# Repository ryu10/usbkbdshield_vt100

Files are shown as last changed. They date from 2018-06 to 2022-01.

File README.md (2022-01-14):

# USB Keyboard Shield for VT100

__Rev. 2.1__

## About

This shield connects a standard USB keyboard to the DEC VT100 terminal.

### Features

* All keys on the VT100 keyboard are mapped to the USB keyboard keys.
* VT100 keyboard LEDs and bell are emulated on the shield PCB.

The Gerber file, BOM, schematics and Arduino sketch for the shield are included in this repo. For the steps to assemble, program and connect the shields, please see the sections below.

__Note:__ this shield uses the USB Host Shield from Circuits@Home.

Please use the information in this repo at your own risk. No warranty or guarantee is provided.

## Required Components

- USB Keyboard Shield for VT100 (the shield from this repo)
- [USB Host Shield by Circuits@Home](https://www.circuitsathome.com/arduino_usb_host_shield_projects/), the "full-sized board"
- Arduino Uno
- Keyboard cable for VT100 (see "Keyboard Cable" below)
- USB Keyboard

## Steps

1. Assemble the shield
2. Build a keyboard cable
3. Program the Arduino
4. Connect the shields and cables

The details of each step are described in the next few sections.

## Assemble the Shield

The USB Keyboard Shield for VT100 can be assembled using the following info:

- PCB Gerber File: [usbkbd_vt100_2_1_gerber.zip](./usbkbd_vt100_2_1_gerber.zip)
- Schematic: [usbkbd_vt100_sch.pdf](./usbkbd_vt100_sch.pdf)
- BOM: [usbkbd_vt100_BOM_2_1.pdf](./usbkbd_vt100_BOM_2_1.pdf)

## Build the Keyboard Cable

To make the keyboard cable, connect these components:

 - 1/4 inch stereo plug/cable
 - 5-pin header connector

__PIN CONNECTIONS__

| Pin | Plug |  Value |
|-|-|-|
| 1* | - | (spk+)* |
| 2* | - | (spk-)* |
| 3 | Tip | +12V |
| 4 | Sleeve | GND |
| 5 | Ring | Signal |

  \* optional

The pin connector is attached to J1 header on the USB Keyboard shield for VT100. The stereo plug is connected to the keyboard port on VT100 terminal.

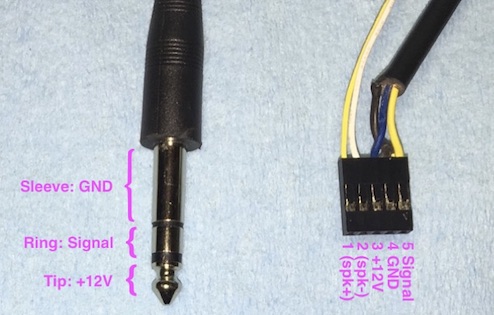
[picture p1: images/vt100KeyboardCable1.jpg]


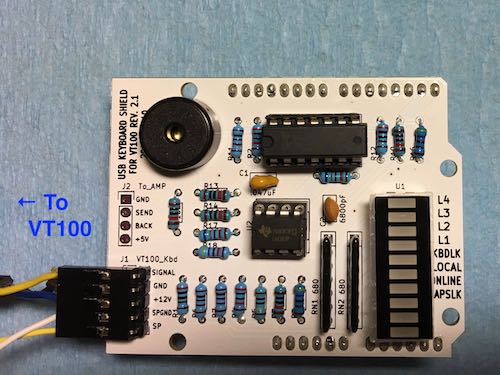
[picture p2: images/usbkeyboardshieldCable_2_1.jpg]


## Program the Arduino Uno

It is recommended to program the Arduino Uno before attaching the shields.

1. Install [USB Host Shield Library 2.0](https://github.com/felis/USB_Host_Shield_2.0) and [Timer1 Library](http://playground.arduino.cc/Code/Timer1) into Arduino IDE.

2. Clone or download this project.

3. Open the sketch `usbkeyboardvt100/usbkeyboardvt100.ino` in Arduino IDE, and program the Arduino Uno.

### Configuration Options

There are two options in `usbkeyboardvt100.ino`:
```
// SWAPCAPS: If defined, LeftCtrl and CapsLock are swapped on USB Keyboard.
#define SWAPCAPS

// SWAPLFBAR: If defined, swap LineFeed and '|\' key codes for VT100.
//#define SWAPLFBAR
```

Comment out/uncomment the `#define` lines as needed.

## Connect the Shields and Cables

1. Connect the USB keyboard to the USB connector on the USB Host Shield.
2. Connect the keyboard cable for VT100 to the J1 header on the USB Keyboard Shield.
3. Connect the keyboard cable to the keyboard port on VT100 terminal.
4. Stack and connect the Arduino Uno, the USB Host Shield, and the USB Keyboard Shield, in this order, from the bottom to the top (see the iamge below).
5. No external power supply is needed. The power is supplied via the VT100 keyboard cable.

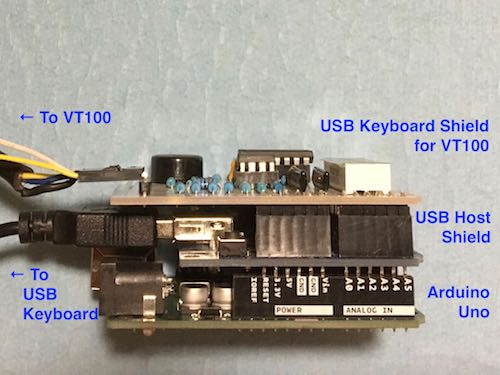
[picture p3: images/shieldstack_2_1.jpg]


## Key Mappings

Some hard-to-guess keys:

| VT100 Key | USB Keyboard Key |
|-|-|
| SET UP | F1, SysRq |
| CTRL | Caps Lock |
| CAPS LOCK | Left Ctrl |
| BREAK | Break |
| LINE FEED | End |
| NO SCROLL | Scroll Lock |
| PF1 | Num Lock, F9 |
| PF2 | (numpad) /, F10 |
| PF3 | (numpad) *, F11 |
| PF4 | Page Up, F12 |
|(numpad) , | (numpad) + |

The key mappings are defined in `usb_key_tbl[]` in `usbkeyboardvt100.h`. Also see "Configuration Options" above.

## Reference Configuration

The following configuration was used during development of this shield:

- USB Host Shield 2.0
- Arduino Uno R3
- VT100-WA / VT-180
- USB Keyboards: HP K1500 / Logitech K310

## Known Issues

1. Keyboard connected via a USB hub is not supported.

## GPL

The code is released under the GNU General Public License.

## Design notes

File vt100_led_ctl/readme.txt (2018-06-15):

vt100_led_ctl:

This directory contains two files that control VT100 keyboard LED's:

1.led_all_on.txt ... contains the ESC sequence that turns on L1 - L4.
0.led_all_off.txt ... contains the ESC sequence that turns off L1 - L4.

To turn on/off the keyboard LED's, display the file contents on the VT100 session with the host machine.

Example:

% cat 1.led_all_on.txt
% cat 0.led_all_off.txt

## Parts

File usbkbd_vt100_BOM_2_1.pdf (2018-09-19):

### USB Keyboard Shield for VT100 Rev. 2.1: Shield Components

Ref | Qty | Value | Desc | Mouser P/N | Mouser URL
C1 | 1 | .047uF | Capacitor | 810-FA16C0G2A473JRU6 | https://www.mouser.com/ProductDetail/TDK/FA16C0G2A473JRU06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
C2 | 1 | 6800pF | Capacitor | 594-S682M43Z5UN63L0R | https://www.mouser.com/ProductDetail/Vishay-BC-Components/S682M43Z5UN63L0R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
J1 | 1 | VT100_Kbd | 5pin Header, angled | 538-90121-0772 | https://www.mouser.com/ProductDetail/Molex/22-28-6220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
J2 | 1 | To_AMP | 4pin Header, straight | (included)
R1 R12 | 2 | 2k | 1/4w Resistors | 660-MF1/4LCT52R202J | https://www.mouser.com/ProductDetail/KOA-Speer/MF1-4LCT52R202J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
R2 R4 | 2 | 20k | 1/4w Resistors | 660-MF1/4LCT52R203J | https://www.mouser.com/ProductDetail/KOA-Speer/MF1-4LCT52R203J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
R3 R9 R10 R13 R14 | 5 | 10k | 1/4w Resistors | 660-MF1/4LCT52R103J | https://www.mouser.com/ProductDetail/KOA-Speer/MF1-4LCT52R103J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
R5 | 1 | 1M | 1/4w Resistors | 660-MF1/4LCT52R105J | https://www.mouser.com/ProductDetail/KOA-Speer/MF1-4LCT52R105J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
R6 R7 R11 | 3 | 1k | 1/4w Resistors | 660-MF1/4LCT52R102J | https://www.mouser.com/ProductDetail/KOA-Speer/MF1-4LCT52R102J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
R8 R16 | 2 | 4k7 | 1/4w Resistors | 660-MF1/4LCT52R472J | https://www.mouser.com/ProductDetail/KOA-Speer/MF1-4LCT52R472J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
R15 R17 | 2 | 68k | 1/4w Resistors | 660-MF1/4LCT52R683G | https://www.mouser.com/ProductDetail/KOA-Speer/MF1-4LCT52R683G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
R18 | 1 | 47k | 1/4w Resistors | 660-MF1/4LCT52R473J | https://www.mouser.com/ProductDetail/KOA-Speer/MF1-4LCT52R473J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
RN1 RN2 | 2 | 680 | Resistor Network | 652-4607X-1LF-680 | https://www.mouser.com/ProductDetail/Bourns/4607X-101-681LF?qs=sGAEpiMZZMvrmc6UYKmaNSh80pCcMnLalccmFXycrCo%3d
SHIELD1 | 1 | (PCB) | USB Keyboard Shield for VT100 PCB | (order separately)
U1 | 1 | LED10ARRAY | DIP 20pin (10 element) LED array | 859-LTA-1000P | https://www.mouser.com/ProductDetail/Lite-On/LTA-1000P?qs=sGAEpiMZZMuu2qEGwSNRoHgghBOHds4Sh92U2lfwZ%2fE%3d
U2 | 1 | LM393 | Comparator | 512-LM393N | https://www.mouser.com/ProductDetail/ON-Semiconductor-Fairchild/LM393N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
U3 | 1 | 74LS06N | OC Inverter TTL | 595-SN74LS06N | https://www.mouser.com/ProductDetail/Texas-Instruments/SN74LS06N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
(U2 Socket) | 1 | 8pin dip socket | IC Socket | 474-PRT-07937 | https://www.mouser.com/ProductDetail/SparkFun/PRT-07937?qs=sGAEpiMZZMuWWq7rhECaKbdYmmvobPIZ8h49BK4NUJo%3d
(U3 Socket) | 1 | 14pin dip socket | IC Socket | 571-1-2199298-3 | https://www.mouser.com/ProductDetail/TE-Connectivity/1-2199298-3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
U4 | 1 | BUZZER | Piezo Buzzer, terminal pitch 7.6mm | 490-CEP-1153 | https://www.mouser.com/ProductDetail/CUI/CEP-1153?qs=sGAEpiMZZMsqIr59i2oRcnHFPeYqSr7todeow%2fSoHSE%3d
J3, J4 | 2 | Shield Header | 1x6 pin headers, straight | 571-3-826936-2 | https://www.mouser.com/ProductDetail/TE-Connectivity-AMP/3-826936-2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
J5, J6 | 2 | Shield Header | 1x8 pin headers, straight | (included)

1

## USB Keyboard Shield for VT100 Rev. 2.1: Other Components

Name | Qty | Desc | Amazon URL #1 | Amazon URL #2
Stereo cable | 1 | 1/4-inch Stereo Plugs & Cable | https://www.amazon.com/Hosa-CSS-105-inch-SameBalanced-Interconnect/dp/B000068NYG
5pin conn. | 1 | 5 pin Connectors | https://www.amazon.com/uxcell-2-54mm-Pitch-Female-Adapter/dp/B00W948IDG
Arduino Uno R3 | 1 | Arduino Uno R3 or compatible | https://www.amazon.com/Arduino-A000066-ARDUINO-UNO-R3/dp/B008GRTSV6 https://www.amazon.com/dp/B01EWOE0UU/r
USB Host Shield | 1 | USB Host Shield 2.0 or compatible | https://www.amazon.com/SainSmart-Android-Arduino-Mega2560-Duemilanove/dp/B006J4G000 https://www.amazon.com/LM-YN-Arduino-Support-Android/dp/B0777DR3T6

1

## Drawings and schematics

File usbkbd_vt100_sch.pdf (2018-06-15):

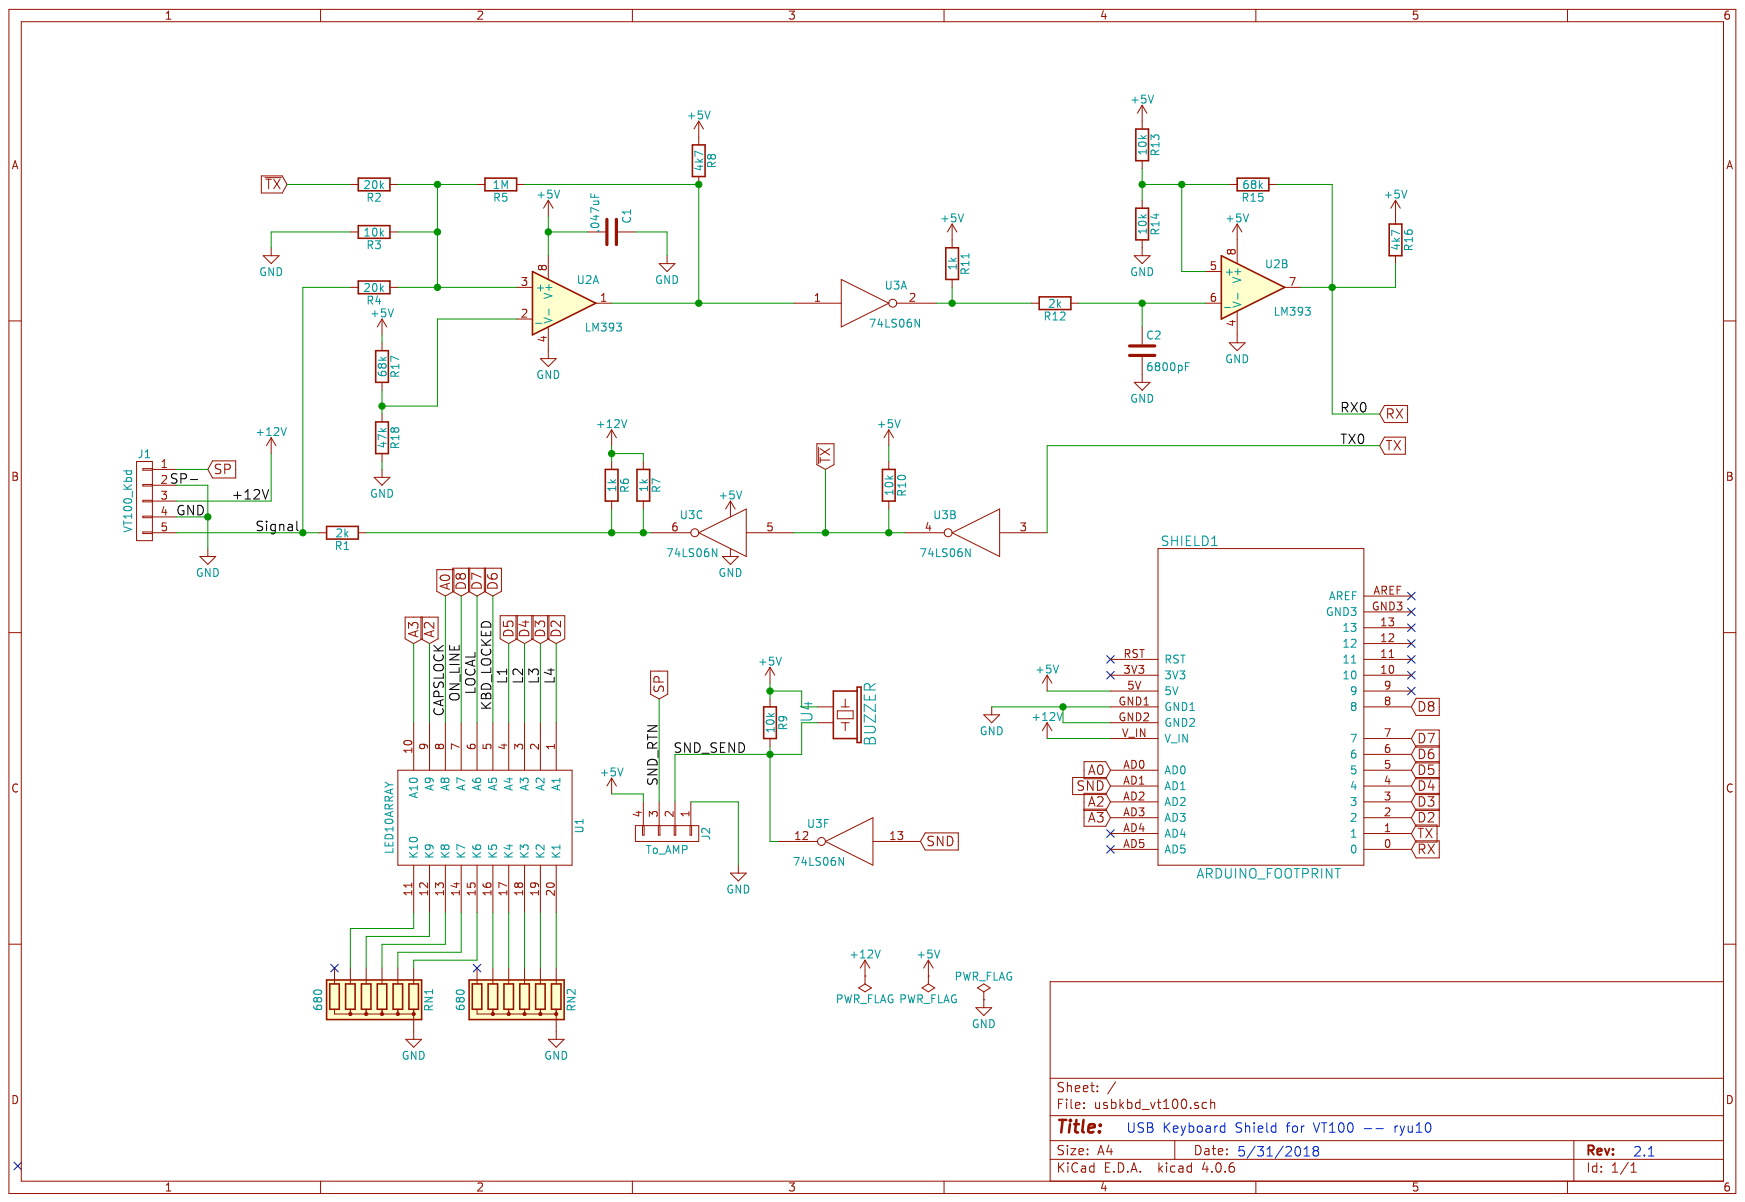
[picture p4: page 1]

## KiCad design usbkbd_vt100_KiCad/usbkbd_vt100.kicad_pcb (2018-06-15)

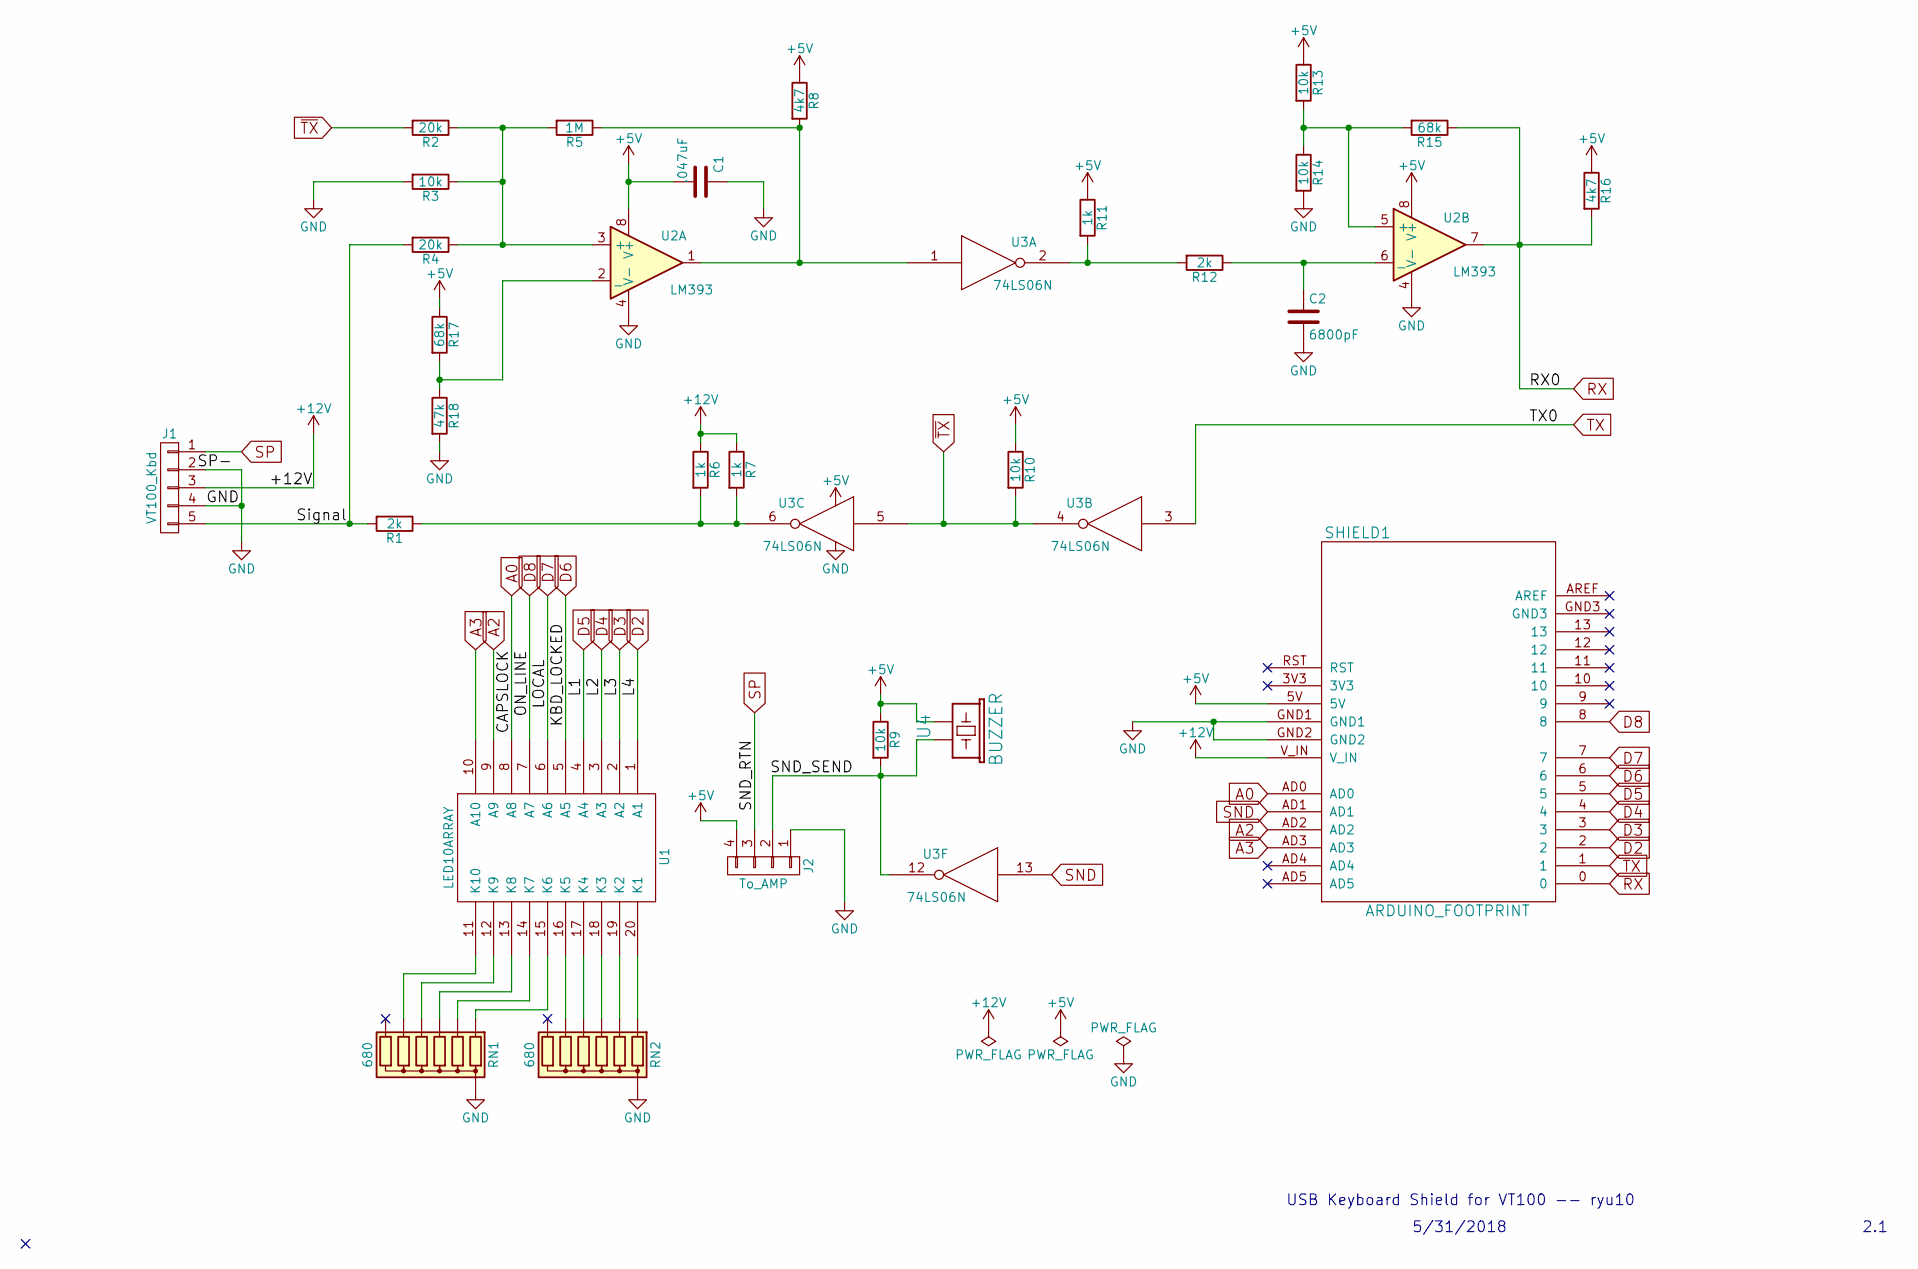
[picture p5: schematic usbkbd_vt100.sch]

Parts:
C1: .047uF; C_Disc_D5.0mm_W2.5mm_P2.50mm
C2: 6800pF; C_Disc_D5.0mm_W2.5mm_P2.50mm
J1: VT100_Kbd; Pin_Header_Angled_1x05
J2: To_AMP; Pin_Header_Straight_1x04
R1, R12: 2k; R_Axial_DIN0204_L3.6mm_D1.6mm_P7.62mm_Horizontal
R2, R4: 20k; R_Axial_DIN0204_L3.6mm_D1.6mm_P7.62mm_Horizontal
R3, R9, R10, R13, R14: 10k; R_Axial_DIN0204_L3.6mm_D1.6mm_P7.62mm_Horizontal
R5: 1M; R_Axial_DIN0204_L3.6mm_D1.6mm_P7.62mm_Horizontal
R6, R7, R11: 1k; R_Axial_DIN0204_L3.6mm_D1.6mm_P7.62mm_Horizontal
R8, R16: 4k7; R_Axial_DIN0204_L3.6mm_D1.6mm_P7.62mm_Horizontal
R15, R17: 68k; R_Axial_DIN0204_L3.6mm_D1.6mm_P7.62mm_Horizontal
R18: 47k; R_Axial_DIN0204_L3.6mm_D1.6mm_P7.62mm_Horizontal
RN1, RN2: 680; R_Array_SIP7
SHIELD1: ARDUINO_FOOTPRINT; ARDUINO_SHIELD_NOICSP
U1: LED10ARRAY; DIP-20_W7.62mm
U2: LM393; DIP-8_W7.62mm_Socket
U3: 74LS06N; DIP-14_W7.62mm_Socket
U4: BUZZER; Buzzer_12x9.5RM7.6

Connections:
+5V: C1.2, J2.4, R8.1, R9.1, R10.1, R11.1, R13.1, R16.1, R17.1, SHIELD1.5V, U2.8 (V+), U3.14 (VCC), U4.1 (POS)
+12V: J1.3, R6.1, R7.1, SHIELD1.V_IN
/SND_SEND: J2.2, R9.2, U3.12, U4.2 (GND)
/Signal: J1.5, R1.2, R4.2
A0: SHIELD1.AD0, U1.8 (A8)
A2: SHIELD1.AD2, U1.9 (A9)
A3: SHIELD1.AD3, U1.10 (A10)
D2: SHIELD1.2, U1.1 (A1)
D3: SHIELD1.3, U1.2 (A2)
D4: SHIELD1.4, U1.3 (A3)
D5: SHIELD1.5, U1.4 (A4)
D6: SHIELD1.6, U1.5 (A5)
D7: SHIELD1.7, U1.6 (A6)
D8: SHIELD1.8, U1.7 (A7)
GND: C1.1, C2.2, J1.2, J1.4, J2.1, R3.2, R14.2, R18.2, RN1.1 (common), RN2.1 (common), SHIELD1.GND1, SHIELD1.GND2, U2.4 (V-), U3.7 (GND)
unnamed: C2.1, R12.1, U2.6 (_)
unnamed: R1.1, R6.2, R7.2, U3.6
unnamed: R2.1, R3.1, R4.1, R5.2, U2.3 (+)
unnamed: R5.1, R8.2, U2.1, U3.1
unnamed: R11.2, R12.2, U3.2
unnamed: R13.2, R14.1, R15.2, U2.5 (+)
unnamed: R17.2, R18.1, U2.2 (_)
unnamed: RN1.2 (R1), U1.15 (K6)
unnamed: RN1.3 (R2), U1.14 (K7)
unnamed: RN1.4 (R3), U1.13 (K8)
unnamed: RN1.5 (R4), U1.12 (K9)
unnamed: RN1.6 (R5), U1.11 (K10)
unnamed: RN2.2 (R1), U1.20 (K1)
unnamed: RN2.3 (R2), U1.19 (K2)
unnamed: RN2.4 (R3), U1.18 (K3)
unnamed: RN2.5 (R4), U1.17 (K4)
unnamed: RN2.6 (R5), U1.16 (K5)
RX: R15.1, R16.2, SHIELD1.0, U2.7
SND: SHIELD1.AD1, U3.13
SP: J1.1, J2.3
TX: SHIELD1.1, U3.3
~TX: R2.2, R10.2, U3.4, U3.5

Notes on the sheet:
USB Keyboard Shield for VT100 -- ryu10
2.1
5/31/2018

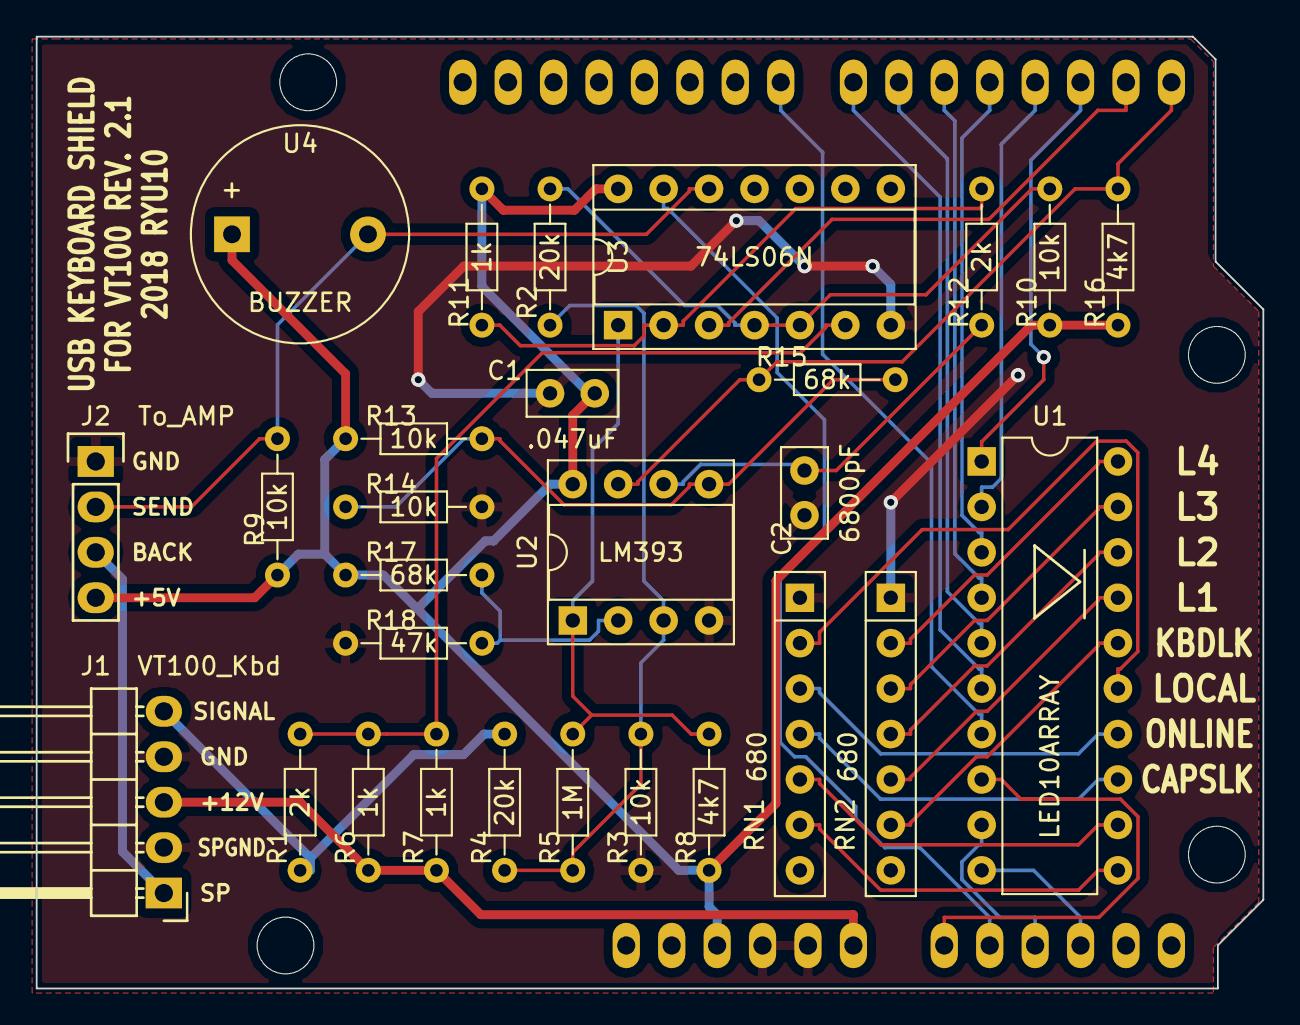
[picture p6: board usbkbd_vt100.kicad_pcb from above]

Board: 2 copper layers, 68.6 x 53.2 mm, 29 parts (0 on the bottom side), 37 nets.

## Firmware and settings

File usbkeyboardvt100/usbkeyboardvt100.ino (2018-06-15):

/*
 *  usbkeyboardvt100.ino
 */

//
// GLOBAL OPTIONS
//

// SWAPCAPS: If defined, LeftCtrl and CapsLock are swapped on USB Keyboard.
#define SWAPCAPS

// SWAPLFBAR: If defined, swap LineFeed and '|\' key codes for VT100.
//#define SWAPLFBAR

//
// END of GLOBAL OPTIONS
//

#include "usbkeyboardvt100.h"

#include <hidboot.h>
#include <usbhub.h>
#include <hiduniversal.h>

#include <TimerOne.h>

// Satisfy the IDE, which needs to see the include statment in the ino too.
#ifdef dobogusinclude
#include <spi4teensy3.h>
#endif
#include <SPI.h>

// There are seven VT100 standard LED's. Another LED for CapsLock.
#define LED_0 2 // LED 4
#define LED_1 3 // LED 3
#define LED_2 4 // LED 2
#define LED_3 5 // LED 1
#define LED_4 6 // KBD LOCKED
#define LED_5 7 // LOCAL
#define LED_6 8 // ON LINE
#define LED_7 A0 // CapsLock
// Two extra LED's are not used
// #define LED_8 A2 // Unused
// #define LED_9 A3 // Unused

// Speaker output
#define SPEAKER A1 // Speaker output
#define SPK_INTERVAL 625 // T = 625us x2 = 1.25ms, 800Hz

// Status byte sent by VT100
int inData;
volatile byte vt100_command = 0x00;

// Whether CapsLock has just been pressed and held or not
int caps_lock_held = 0;

// Vt100 keyboard LED process status
int led_pins[] = {LED_0, LED_1, LED_2, LED_3, LED_4, LED_5, LED_6, LED_7};
int led_current = 0;
byte led_status = 0x00;
byte led_mask;

// Speaker toggle status, updated by Timer1 interrupt
volatile byte spk_status = 0x00;

// Send back key down information to VT100
void vt100_sendback_status(){
  int i;

  for(i=1; i<VT100KEYS; i++){  // Skip vt100_key_status[0] which is always open
    if(vt100_key_status[i]){
      Serial.write(vt100_key_tbl[i]);
    }
  }
  Serial.flush();
}

// Update LED status
void update_led_off(){

  digitalWrite(led_pins[led_current], LOW); // Turn off current LED for dynamic LED control

}

void update_led_on(){

  led_current = (led_current + 1) % 8;  // Next LED

  led_mask = 0x01 << led_current;
  if(led_status & led_mask){
    digitalWrite(led_pins[led_current], HIGH);
  }else{
    digitalWrite(led_pins[led_current], LOW);
  }

}

// Timer1 Interrupt Handler to toggle Speaker
void check_beep(){

  if(vt100_command & 0x80){
    if(spk_status){
      digitalWrite(SPEAKER, HIGH);
    }else{
      digitalWrite(SPEAKER, LOW);
    }
    spk_status = ~spk_status;
  }

}

//
// USB HID code based on
// https://github.com/felis/USB_Host_Shield_2.0/tree/master/examples/HID/USBHIDBootKbd
//

USB     Usb;
// USBHub     Hub(&Usb);
HIDBoot<USB_HID_PROTOCOL_KEYBOARD>    HidKeyboard(&Usb);

//
// USB HID - KbdRptParser class
//

class KbdRptParser : public KeyboardReportParser
{
  protected:
    void OnControlKeysChanged(uint8_t before, uint8_t after);
    void OnKeyDown  (uint8_t mod, uint8_t key);
    void OnKeyUp  (uint8_t mod, uint8_t key);
    uint8_t HandleLockingKeys(USBHID* hid, uint8_t key);

};

void KbdRptParser::OnControlKeysChanged(uint8_t before, uint8_t after) {

  MODIFIERKEYS beforeMod;
  *((uint8_t*)&beforeMod) = before;
  MODIFIERKEYS afterMod;
  *((uint8_t*)&afterMod) = after;

#ifdef SWAPCAPS
// Left Ctrl as CapsLock
  if (beforeMod.bmLeftCtrl != afterMod.bmLeftCtrl) { // L-Ctrl status changed
    if(afterMod.bmLeftCtrl){ // Ctrl key down
      if(vt100_key_status[VT100CAPSLOCK] == 0){
        vt100_key_status[VT100CAPSLOCK] = 1;
        led_status |= 0x80; // LED_7: CapsLock on
        caps_lock_held = 1;
      }
    }else{ // Ctrl key up
      if(caps_lock_held == 1){ // CapsLock has just been turned on
          caps_lock_held = 0;
       }else{ // CapsLock is released
        vt100_key_status[VT100CAPSLOCK] = 0;
        led_status &= ~0x80; // LED_7: CapsLock LED off
//        caps_lock_held = 0;
      }
    }
  }

// Update both R-CTRL and SHIFT anyway
  if (afterMod.bmRightCtrl) { // Test RightCtrl
        vt100_key_status[VT100CTRL] = 1;
  }else{
        vt100_key_status[VT100CTRL] = 0;
  }
#else // SWAPCAPS undefined
  if (afterMod.bmLeftCtrl||afterMod.bmRightCtrl) { // Test Ctrl keys
        vt100_key_status[VT100CTRL] = 1;
  }else{
        vt100_key_status[VT100CTRL] = 0;
  }
#endif // SWAPCAPS

  if (afterMod.bmLeftShift||afterMod.bmRightShift) { // Test Shift keys
        vt100_key_status[VT100SHIFT] = 1;
  }else{
        vt100_key_status[VT100SHIFT] = 0;
  }

}

void KbdRptParser::OnKeyDown(uint8_t mod, uint8_t key)
{
  int vt100key_index;

  vt100key_index = usb_key_tbl[key];
  if((vt100key_index > 0) && (vt100key_index < VT100KEYS-1)){

#ifdef SWAPCAPS
    vt100_key_status[vt100key_index] = 1;
#else // SWAPCAPS undefined
    // Check CapsLock first
    if(vt100key_index == VT100CAPSLOCK){
      if(vt100_key_status[VT100CAPSLOCK]==0){
        vt100_key_status[VT100CAPSLOCK] = 1;
        led_status |= 0x80; // LED_7: CapsLock
        caps_lock_held = 1;
      }
    }else{
      vt100_key_status[vt100key_index] = 1;
    }
#endif // SWAPCAPS

  }
}

void KbdRptParser::OnKeyUp(uint8_t mod, uint8_t key)
{
  int vt100key_index;

  vt100key_index = usb_key_tbl[key];
  if((vt100key_index > 0) && (vt100key_index < VT100KEYS-1)){

#ifdef SWAPCAPS // CapsLock is checked in OnControlKeysChanged()
      vt100_key_status[vt100key_index] = 0;
#else // SWAPCAPS undefined
    // Check CapsLock first
    if(vt100key_index == VT100CAPSLOCK){
      if(caps_lock_held == 1){
          caps_lock_held = 0;
      }else{
        if(vt100_key_status[VT100CAPSLOCK]==1){
          vt100_key_status[VT100CAPSLOCK] = 0;
          led_status &= ~0x80; // LED_7: CapsLock
        }
      }
    }else{
      vt100_key_status[vt100key_index] = 0;
    }
#endif // SWAPCAPS
  }
}

// To override the parent which calls SetReport()
uint8_t KbdRptParser::HandleLockingKeys(USBHID* hid, uint8_t key){
    return 0;
}

;

//
// end of KbdRptParser class
//

KbdRptParser Prs;

//
// SETUP
//

void setup() {
  int i;

// Initialze LED output
  for(i=0; i < 8; i++){
    pinMode(led_pins[i], OUTPUT);
    digitalWrite(led_pins[i], LOW);
  }

// Start VT100 Keyboard UART communication
  Serial.begin(7867);

// Initialze Speaker output
  pinMode(SPEAKER, OUTPUT);
  digitalWrite(SPEAKER, LOW);

// initialze vt100_key_status
  for(i=0; i<VT100KEYS-1; i++){
      vt100_key_status[i] = 0;
  }
  vt100_key_status[VT100KEYS-1] = 1; // Always send <scan end>

// Start Timer Interrupt
  Timer1.initialize(SPK_INTERVAL); // SPK_INTERVAL = 625 for 800Hz
  Timer1.attachInterrupt(check_beep);

// Handle VT100 Power-on Self Test (POST)
#define POST_DELAY 3000 // 3 sec wait before post timeout
  int post_kbd_test = 1;
  int post_time;

  post_time = millis() + POST_DELAY;

  while(post_kbd_test && post_time > millis()){

    update_led_on();

    if(Serial.available() > 0){
      inData = Serial.read();
      if(inData != -1){
        vt100_command = (byte) inData;
        if(vt100_command & 0x40){ // Start scan bit = on
          vt100_sendback_status();
        }
        if(vt100_command == 0xff){ // Beep issued at the end of POST
            post_kbd_test = 2;
        }
        if(vt100_command == 0x00){ // Done beeping
           post_kbd_test = 0; // Break the while loop
        }
      }
    }

    update_led_off();

    led_status = led_status & 0x80 | vt100_command & 0x3f;
    if(led_status & 0x20){ // ON_LINE (bit 6) = ~LOCAL (bit 5)
      led_status &= ~0x40;
    }else{
      led_status |= 0x40;
    }
  } // POST is done

// initialize USB Host Shield
  if (Usb.Init() == -1){
    // If USB initialization fails, indicate error by turning on LED_7
    led_status = 0x80;
    while(true){ // Loop with LED control
      update_led_on();
      delay(15);
      update_led_off();
      delay(3);
    }
  }

//  delay( 200 );
  if(HidKeyboard.SetReportParser(0, &Prs)==false){
    // If HidKeyboard initialization fails, indicate the error by turning on LED_0 and LED_7
    led_status = 0x81;
    while(true){ // Loop with LED control
      update_led_on();
      delay(15);
      update_led_off();
      delay(3);
    }
  }

}

//
// LOOP
//

void loop() {
  int i;

// Update LED array
  update_led_off();

// Read and handle VT100 status byte
  if(Serial.available() > 0){
    inData = Serial.read();
    if(inData != -1){
      vt100_command = (byte) inData;

      if(vt100_command & 0x40){ // Start scan bit = on
        vt100_sendback_status();
       }

      led_status = led_status & 0x80 | vt100_command & 0x3f;
      if(led_status & 0x20){ // ON_LINE (bit 6) = ~LOCAL (bit 5)
        led_status &= ~0x40;
      }else{
        led_status |= 0x40;
      }
    }
  }

// Check beep
//  check_beep(); // is now handled in Timer1 Interrupt

// Update LED array
  update_led_on();

// USB Host Shield tasks
  Usb.Task();

}

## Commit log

2018-06-15 Rev2.1 release for GitHub
    [usbkbd_vt100-B.Cu.gbl, usbkbd_vt100-B.Mask.gbs, usbkbd_vt100-B.SilkS.gbo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]
2018-09-19 Updated the rev2.1 BOM
2018-09-19 Update the BOM
2019-02-21 readme: install step for Timer1
